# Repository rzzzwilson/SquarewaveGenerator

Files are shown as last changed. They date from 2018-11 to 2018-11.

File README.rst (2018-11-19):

SquareGen
=========

This project is a repackaging of the fast risetime Square Wave generator
that I built from the 
`video by W2AEW on YouTube <https://www.youtube.com/watch?v=9cP6w2odGUc>`_.
I originally put this circuit into an enclosure using the "dead bug" style
and it worked pretty well.  Here's the built circuit:

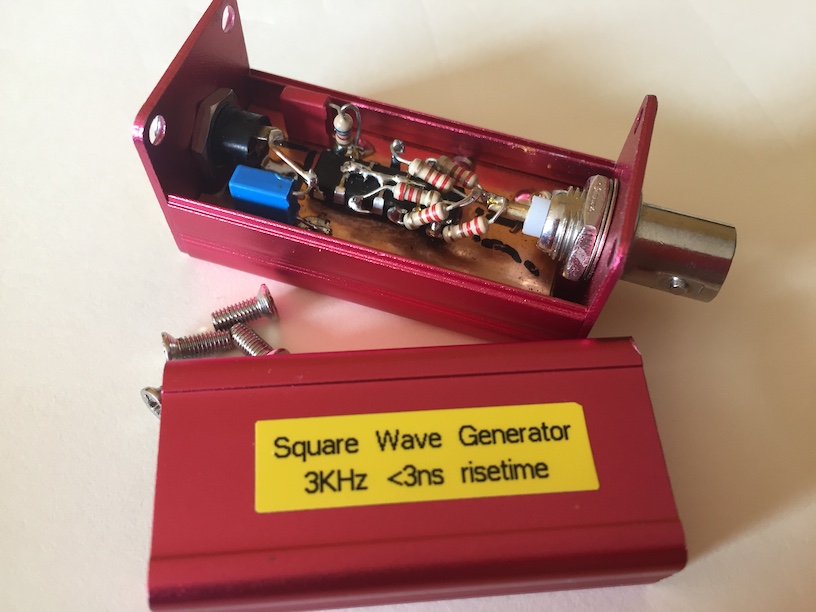
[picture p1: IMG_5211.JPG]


And here's the circuit running on the 'scope:

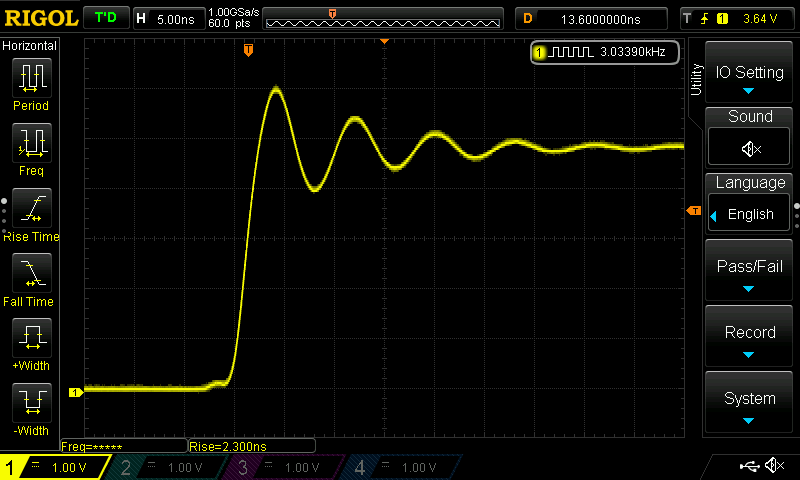
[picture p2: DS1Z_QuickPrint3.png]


Not bad for a cheap little circuit.  It draws less than 3mA at 5volts, unloaded.
About 30mA into a 50 ohm load.

I have been building circuits on PCB lately using the PCB shops in China with
through-hole components, but now I want to get into surface-mounted components
so I'm using this circuit as a guinea-pig.  Using KiCAD here's the schematic:

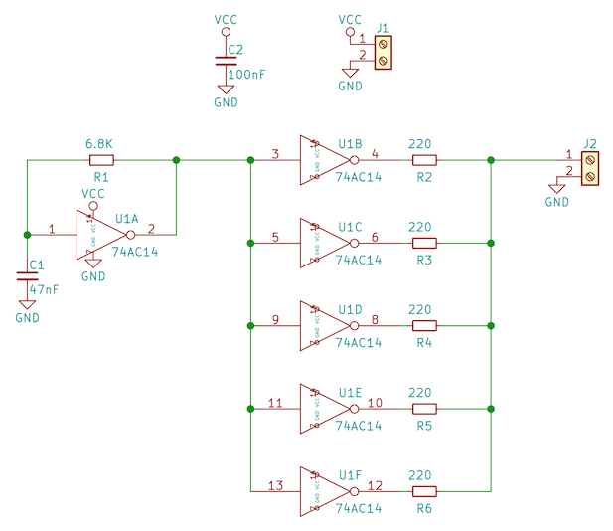
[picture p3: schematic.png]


and the PCB itself:

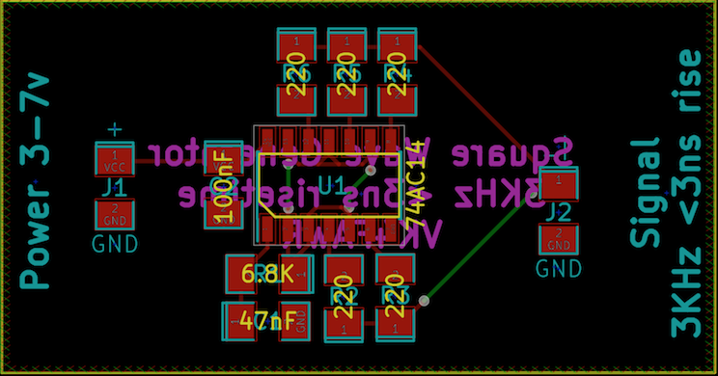
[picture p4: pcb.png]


I'll put the PCB into the same 25x25x50mm enclosure as the first circuit, so the
PCB measures about 44x23mm.  I got the enclosures 
`from here <https://www.aliexpress.com/wholesale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>`_.

18 October 2018
===============

The SMD PCB is back from China and the circuit has been built.  Here is the
assembled board being tested:

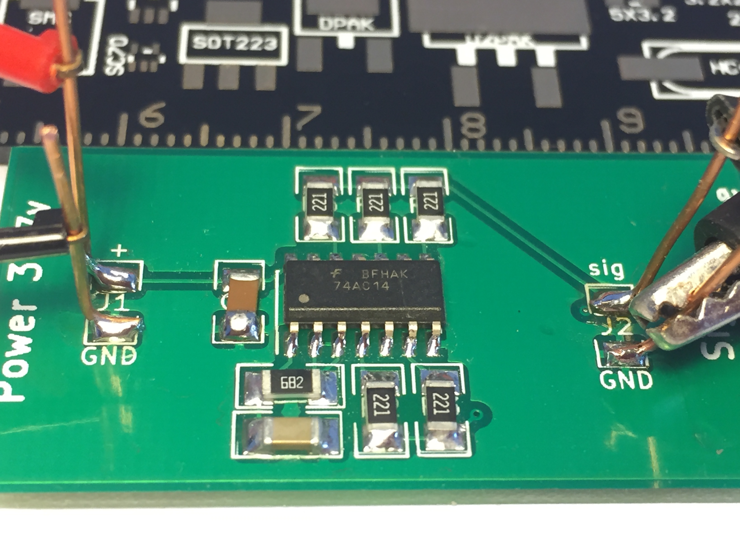
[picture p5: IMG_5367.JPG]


and the board installed in a small 25x25x50mm case:

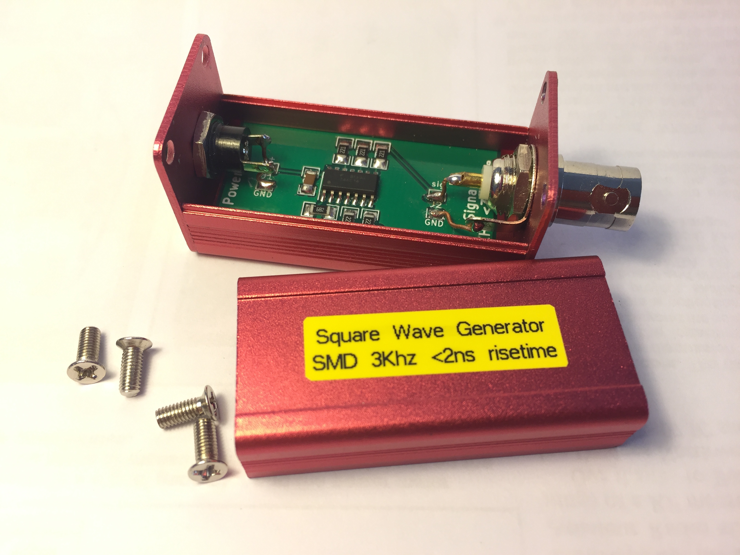
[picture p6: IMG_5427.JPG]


With the generator working into a 50 ohm load it draws about 30mA at 5v.  Here's
a close look at the leading edge of the 3KHz square wave.  Risetime is even
better than the first version at 1.7nS:

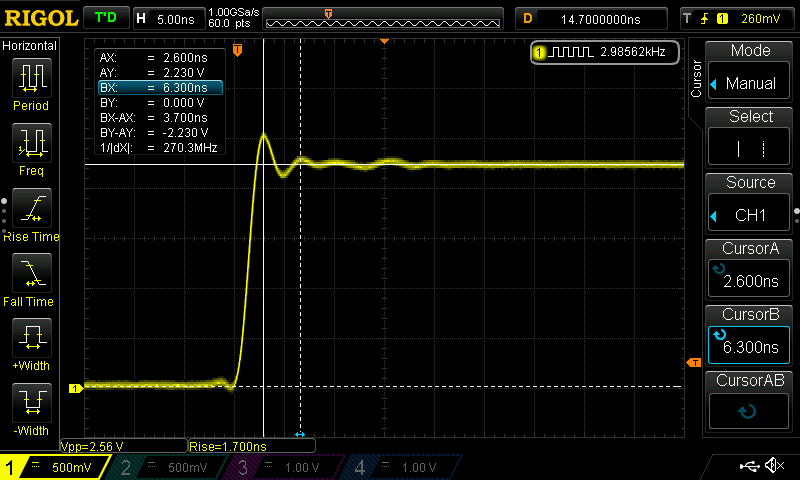
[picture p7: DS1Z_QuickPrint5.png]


Next version
============

The SMD version above works very well, but there are a few things that could be
improved, such as:

* thicker connections on the output side,
* 50 ohm connections to the output pad,
* better power/RF connection pads,
* use a groundplane on the back side of the board.

The board is sized to fit into the 25x25x50mm case *diagonally* which will allow
much shorter connections for power and signal.  Here's the PCB:

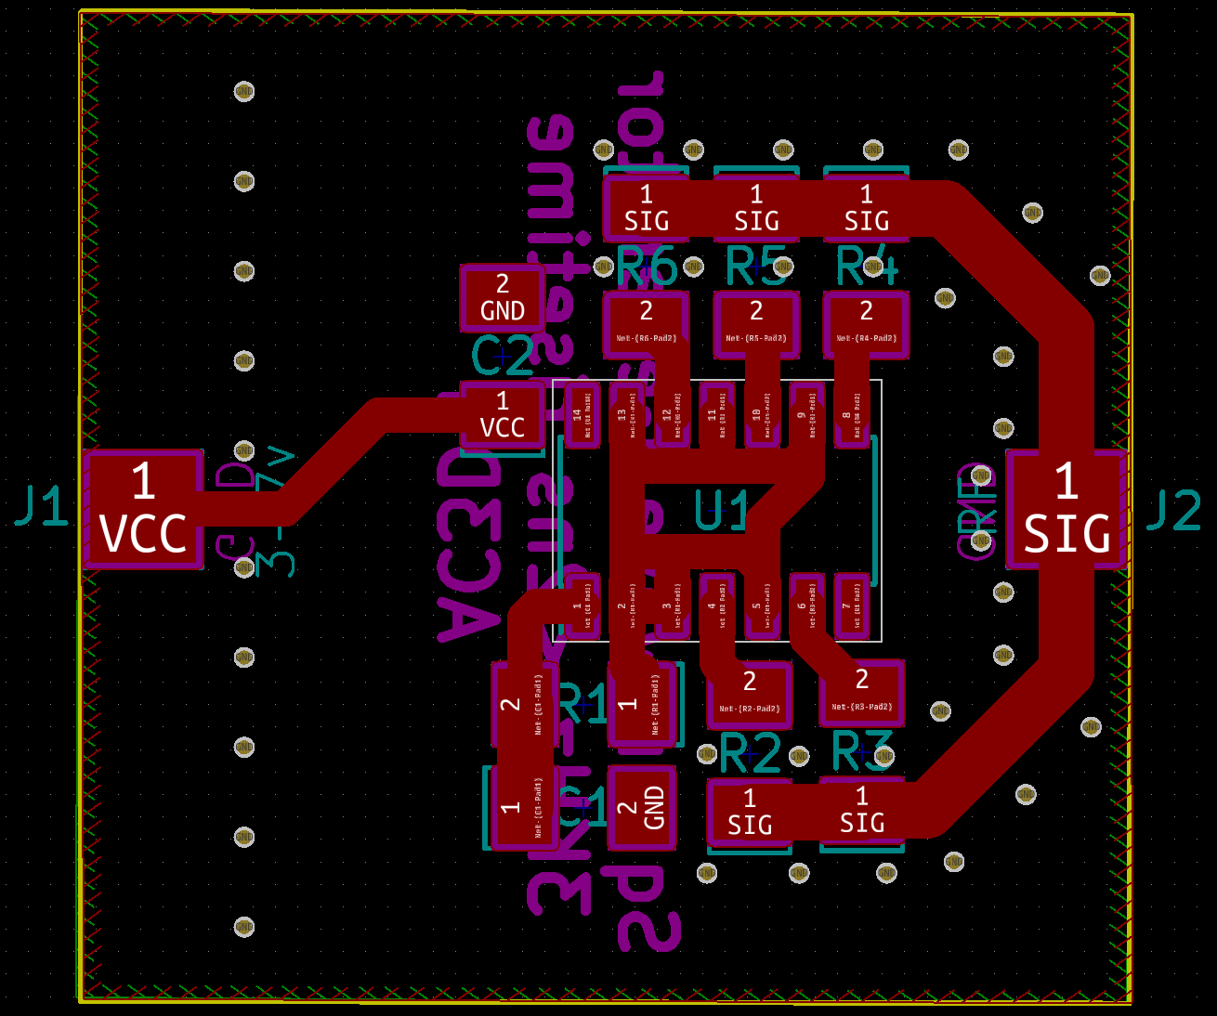
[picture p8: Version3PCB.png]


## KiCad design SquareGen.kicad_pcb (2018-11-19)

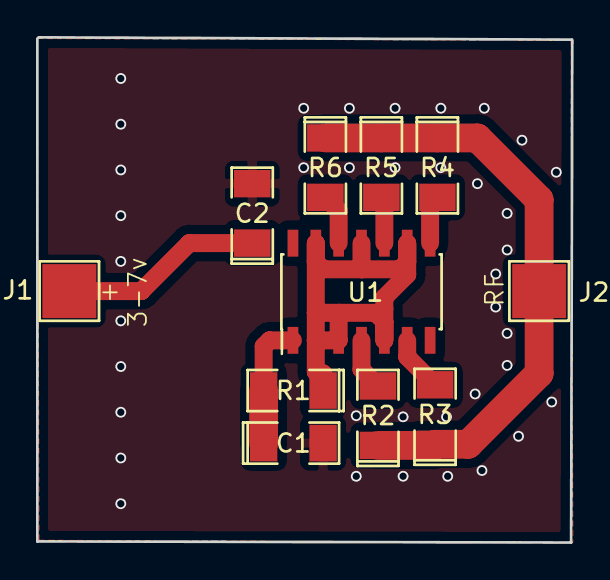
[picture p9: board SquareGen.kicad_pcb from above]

Board: 2 copper layers, 29.7 x 28.1 mm, 11 parts (0 on the bottom side), 10 nets.

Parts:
C1: 47nF; SMD-1206_Pol
C2: 100nF; SMD-1206_Pol
J1, J2: Power_RF_Pads
R1: 6.8K; SMD-1206_Pol
R2, R3, R4, R5, R6: 220; SMD-1206_Pol
U1: 74AC14; SOIC-14_3.9x8.7mm_Pitch1.27mm

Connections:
/SIG: J2.1, R2.1, R3.1, R4.1, R5.1, R6.1
GND: C1.2, C2.2, J1.2, J2.2
unnamed: C1.1, R1.2, U1.1
unnamed: R1.1, U1.2, U1.3, U1.5, U1.9, U1.11, U1.13
unnamed: R2.2, U1.4
unnamed: R3.2, U1.6
unnamed: R4.2, U1.8
unnamed: R5.2, U1.10
unnamed: R6.2, U1.12
VCC: C2.1, J1.1

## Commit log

2018-11-19 Added KiCAD-specific ignores
2018-11-19 Version 3
    [SquareGen.kicad_pcb, SquareGen.sch]
